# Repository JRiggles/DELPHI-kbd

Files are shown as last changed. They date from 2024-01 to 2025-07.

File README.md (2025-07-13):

<p align="center">
    DELPHI_KBD logo in white
</p>

Hardware v1.0.2, Software v1.2.0 &copy; 2022-25[^1] 

*Current version runs the latest KMK as of July 13th '25, and CircuitPython version 9.2.8*

[^1]: Hardware/software versions will (try to) adhere to [SEMVER](https://semver.org/). It is my intention that hardware and software which share a `MAJOR` version will be compatible with one another (e.g., hardware version 1.2.3 will still be compatible with software version 1.0.0)

## Dual Ergolinear Low-Profile Human Interface ##
DELPHI is a minimal split mechanical keyboard designed to combine ergonomics and an ortholinear layout into a small form factor.

<p align="center">
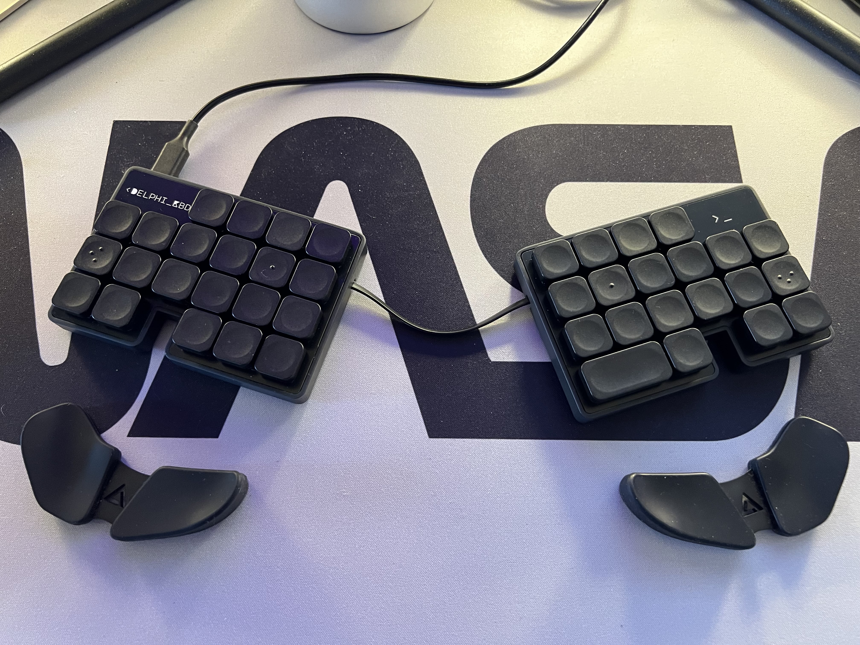
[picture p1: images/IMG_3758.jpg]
Photo of assembled keyboard with PCB plates and the 'HP' version of the 'Edge Case'
    
    <br/>
    <br/>
</p>

<p align="center">
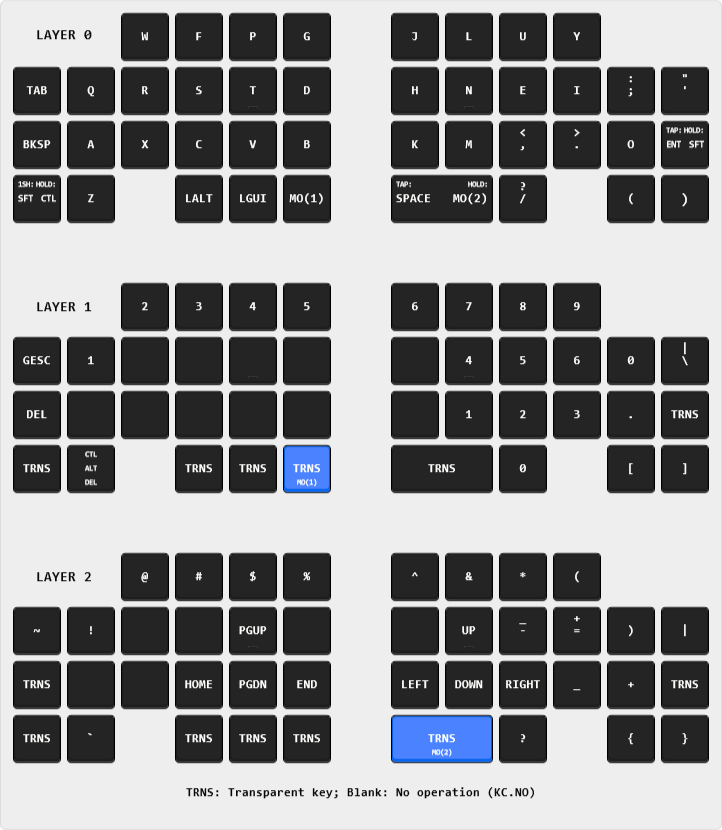
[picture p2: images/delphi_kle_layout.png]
Keyboard Layout Editor layout
    
    <br/>
    <a href="http://www.keyboard-layout-editor.com/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'%3B&@_a:7%3B&=BKSP&=A&=X&=C&=V&=B&_x:1%3B&=K&=M&_a:5%3B&=%3C%0A%0A%0A%0A%0A%0A,&=%3E%0A%0A%0A%0A%0A%0A.&_a:7%3B&=O&_a:4&f:1&fa@:0&:0&:0&:0&:0&:0&:2&:2%3B%3B&=TAP%2F:%0A%0AHOLD%2F:%0A%0A%0A%0AENT%0ASFT%3B&@=1SH%2F:%0A%0AHOLD%2F:%0A%0A%0A%0ASFT%0ACTL&_a:7&f:3%3B&=Z&_x:1%3B&=LALT&=LGUI&=MO(1)&_x:1&a:4&fa@:1&:0&:1%3B&w:2%3B&=TAP%2F:%0A%0AHOLD%2F:%0A%0A%0A%0ASPACE%0AMO(2)&_a:5&f:3%3B&=%3F%0A%0A%0A%0A%0A%0A%2F%2F&_x:1&a:7&f:3%3B&=(&_f:4%3B&=)%3B&@_y:1&c=%23cccccc&t=%23000000&w:2&d:true%3B&=LAYER%201&_c=%231f1f1f&t=%23ffffff&f:3%3B&=2&=3&=4&=5&_x:1%3B&=6&=7&=8&=9%3B&@=GESC&=1&=&=&_n:true%3B&=&=&_x:1%3B&=&_n:true%3B&=4&=5&=6&=0&_a:5%3B&=%7C%0A%0A%0A%0A%0A%0A%5C%3B&@_a:7%3B&=DEL&=&=&=&=&=&_x:1%3B&=&=1&=2&=3&=.&_f:2&fa@:3%3B%3B&=TRNS%3B&@_f:3%3B&=TRNS&_a:5&fa@:1&:1&:0&:0&:0&:0&:1%3B%3B&=CTL%0ADEL%0A%0A%0A%0A%0AALT&_x:1&a:7&f:3%3B&=TRNS&_f:3%3B&=TRNS&_c=%230069ff&a:5&fa@:1&:1%3B%3B&=%0AMO(1)%0A%0A%0A%0A%0ATRNS&_x:1&c=%231f1f1f&a:7&f:3&w:2%3B&=TRNS&_f:3%3B&=0&_x:1&f:3%3B&=%5B&_f:3%3B&=%5D%3B&@_y:1&c=%23cccccc&t=%23000000&f:4&w:2&d:true%3B&=LAYER%202&_c=%231f1f1f&t=%23ffffff&f:3%3B&=%2F@&=%23&=$&=%25&_x:1%3B&=%5E&=%2F&&=*&=(%3B&@=~&=!&=&=&_n:true%3B&=PGUP&=&_x:1%3B&=&_n:true%3B&=UP&_a:5%3B&=%2F_%0A%0A%0A%0A%0A%0A-&=+%0A%0A%0A%0A%0A%0A%2F=&_a:7%3B&=)&=%7C%3B&@=TRNS&=&=&=HOME&=PGDN&=END&_x:1%3B&=LEFT&=DOWN&=RIGHT&=%2F_&=+&_f:2&fa@:3%3B%3B&=TRNS%3B&@_f:3%3B&=TRNS&=%60&_x:1%3B&=TRNS&=TRNS&=TRNS&_x:1&c=%230069ff&a:5&f2:1&w:2%3B&=%0AMO(2)%0A%0A%0A%0A%0ATRNS&_c=%231f1f1f&a:7%3B&=%3F&_x:1%3B&=%7B&=%7D%3B&@_t=%23000000&w:13&d:true%3B&=TRNS%2F:%20Transparent%20key%2F%3B%20Blank%2F:%20No%20operation%20(KC.NO)">Layout</a> (yes, it's <a href="https://en.wikipedia.org/wiki/Colemak">COLEMAK</a>)
</p>

## Features
- "Ergolinear" layout combines an ortholinear (columnar) layout with staggered pinky rows for ergonomics
  - Outermost 2 columns on each half are staggered down 1U for easier reach
- Kailh "Choc" low-profile mechanical switches
- Hot-swappable sockets
- Split board (optional, I suppose)
- 40-42 keys (40%) total [20-21 keys on each half]
- Thumb cluster on each half supports a 3&times;1U or a 1&times;1U + 1&times;2U layout
- Wired connection to PC (either half can be connected via USB)
- Wired connection between Left and Right boards (via Adafruit STEMMA QT)
- Dimensions: 4.65" &times; 3.15" (118mm &times; 80mm) [each half]
- [Adafruit QT Py RP2040 microcontroller](https://www.adafruit.com/product/4900) (2&times;)
  - USB C
  - Raspberry Pi RP2040 chip
  - STEMMA QT connector (a.k.a. Qwiic)
> [!IMPORTANT]
> A [STEMMA QT cable](https://www.adafruit.com/product/5385) (or compatible equivalent, such as a SparkFun Qwiic cable) is required to connect the halves<br/>300mm or 400mm length is recommended. The cable pictured above is 300mm long.
  <br/>

  > DELPHI ***might*** also work with the SAMD21 [Adafruit QT PY](https://www.adafruit.com/product/4600) as long as you solder on the "optional"<sup>*</sup> [2MB SPI Flash IC](https://www.adafruit.com/product/4763), but I haven't been able to get this board to work on Windows 11 (YMMV). 
  >
  > <sup>*</sup>KMK firmware will not fit on this board without the extra Flash memory.

## PCB Renders
<p align="center">
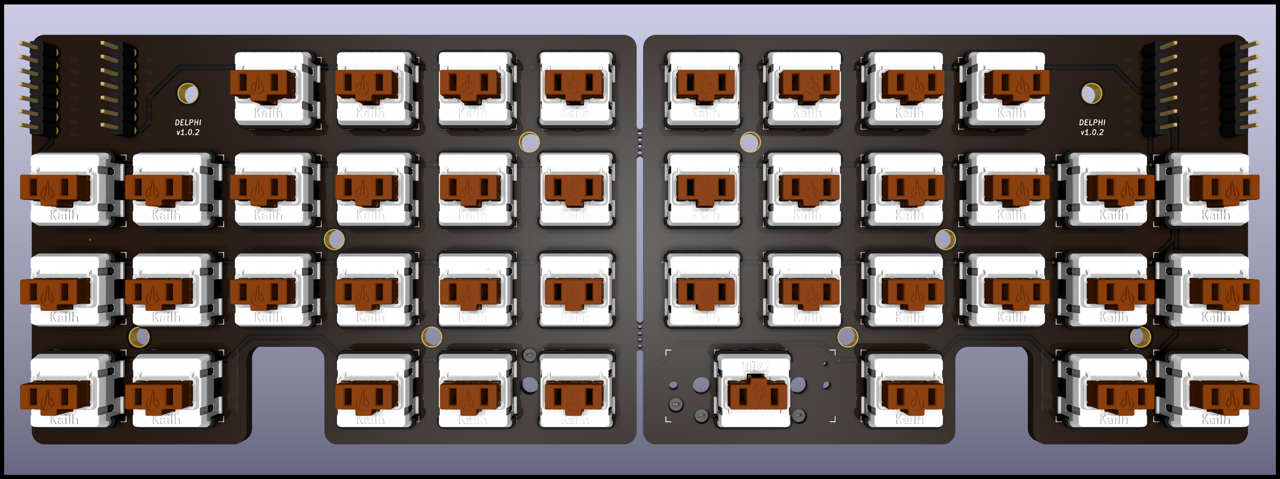
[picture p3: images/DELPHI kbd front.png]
PCB render front view
    
    <br/>
    PCB top view
</p>

<p align="center">
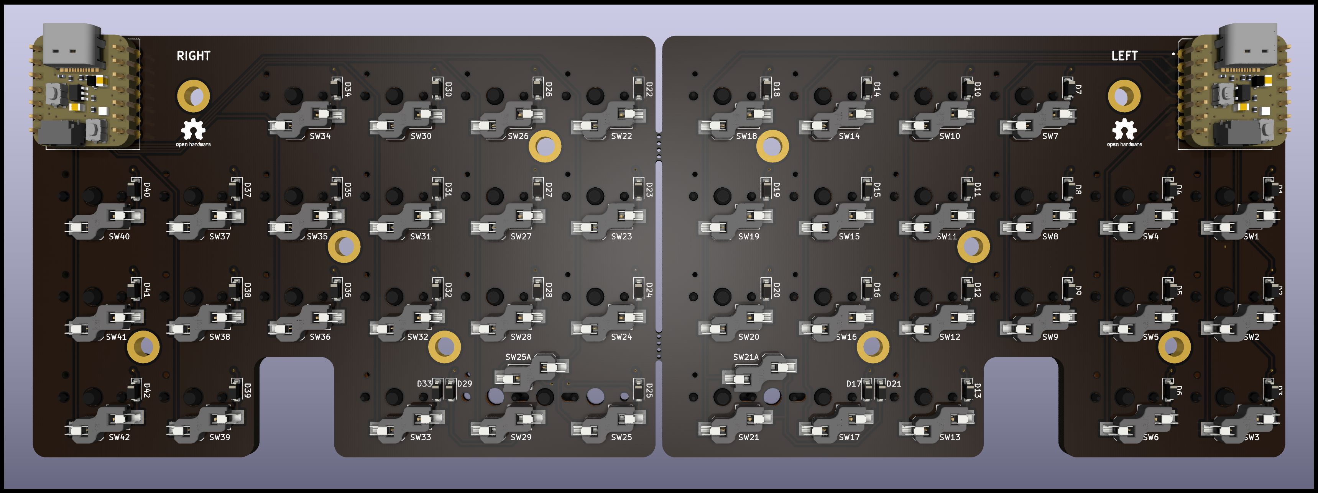
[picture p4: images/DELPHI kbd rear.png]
PCB render rear view
    
    <br/>
    PCB bottom view
</p>

## Accessories
### PCB top and bottom [plates](https://github.com/JRiggles/DELPHI-kbd/blob/main/plates) 
> [!NOTE]
>  - One plate set covers one *half* of DELPHI - you'll need to use two sets to cover both halves
>  - The main PCB mounts to bottom plate via qty. 5 M2&times;6mm standoffs ***per-half***
>  - It's recommended that you use at least the bottom plate on each half of DELPHI in order to protect the components and avoid hitting the microcontroller's reset / boot buttons 
 
<p align="center">
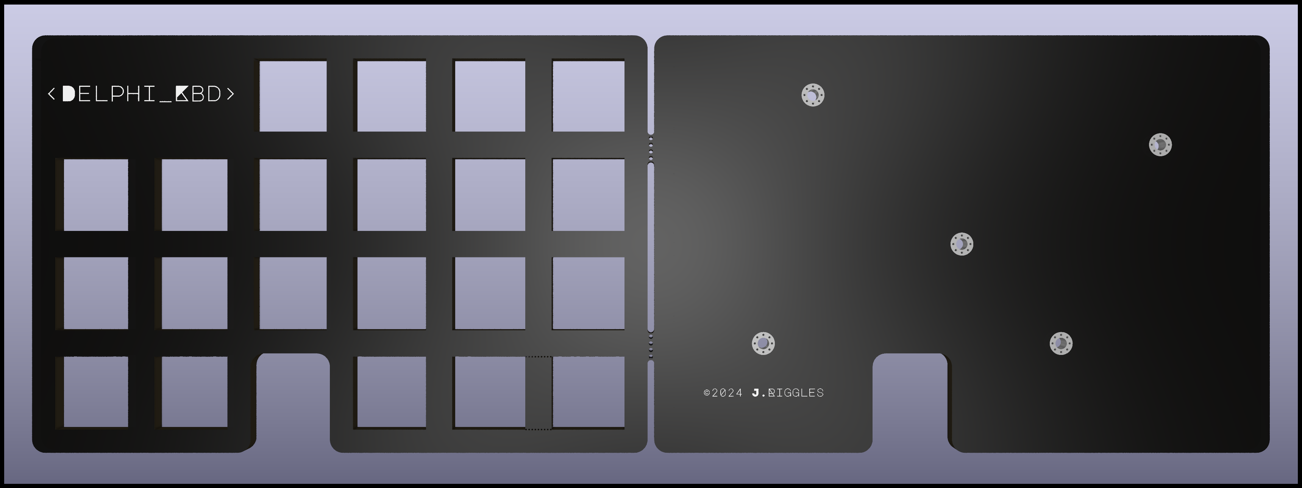
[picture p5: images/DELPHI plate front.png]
PCB render front view
    
    <br/>
    Plates front view (i.e., left side top and bottom plates) - <a href="https://github.com/JRiggles/DELPHI-kbd/blob/main/images/Plates%20LEFT.jpeg">photo here</a>
</p>

<p align="center">
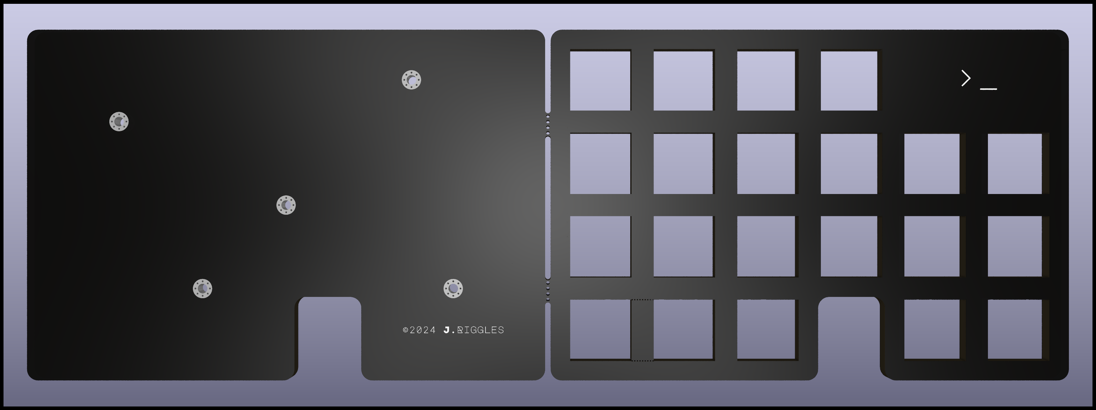
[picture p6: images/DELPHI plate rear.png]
PCB render rear view
    
    <br/>
    Plates rear view (i.e., right side bottom and top plates) - <a href="https://github.com/JRiggles/DELPHI-kbd/blob/main/images/Plates%20RIGHT.jpeg">photo here</a>
</p>

### 3D printable case: the ["Edge Case"](https://github.com/JRiggles/DELPHI-kbd/blob/main/cases) 
> [!NOTE]
>  - This case assumes you're using at least the bottom PCB plate (in addition to the main PCB)
>  - The STL is for the LEFT side; it will need to be *mirrored* in your slicer of choice to accommodate the RIGHT side

There are two case variants:
  - Edge Case LP (low-profile, lines up with bottom plate and main PCB)
  - Edge Case HP (high-profile, lines up with bottom plate and top plate; pictured above on assembled keyboard)
  > Presupported Lychee Slicer scene files (\*.lys) are included for each case variant
  
## Software
- [CircuitPython 8.2.9 or later](https://circuitpython.org/board/adafruit_qtpy_rp2040/)
- [KMK Firmware](https://github.com/KMKfw/kmk_firmware)

## Software Setup

The setup for DELPHI essentially follows the [TL;DR Quick start guide]([https://kmkfw.io/Getting_Started/](https://github.com/KMKfw/kmk_firmware/blob/main/docs/en/Getting_Started.md)) for KMK, with some changes:

1. Connect the **LEFT** half of DELPHI to your computer via USB
2. Download and install [CircuitPython](https://circuitpython.org/board/adafruit_qtpy_rp2040/) for the Adafruit QT Py RP2040
3. [Rename](https://learn.adafruit.com/welcome-to-circuitpython/renaming-circuitpy) the `CIRCUITPY` USB drive to `DELPHI_L` *(must be exactly this!)*
4. Download and unzip [KMK Firmware](https://github.com/KMKfw/kmk_firmware)
5. Download DELPHI [boot.py](https://github.com/JRiggles/DELPHI-kbd/blob/main/firmware/boot.py)
6. Download DELPHI [main.py](https://github.com/JRiggles/DELPHI-kbd/blob/main/firmware/main.py)
7. Copy the `kmk` folder to the root of the `DELPHI_L` drive[^2]
8. Copy `boot.py` to the root of the `DELPHI_L` drive
9. Copy `main.py` to the root of the `DELPHI_L` drive
10. Eject the `DELPHI_L` USB drive and disconnect it from your computer

Repeat these steps for the **RIGHT** half of DELPHI, being sure to rename the `CIRCUITPY` drive to `DELPHI_R` at step 3 *(must be exactly this!)*

[^2]: As of firmware v1.1.0, DELPHI hides the CircuitPython USB drive by default. To mount the drive, hold the corresponding homing key (e.g. "T" on the left half or "N" on the right half) while connecting the board. To disable this feature, simply leave the `boot.py` file empty.

##

### TODO
- [ ] Build guide?

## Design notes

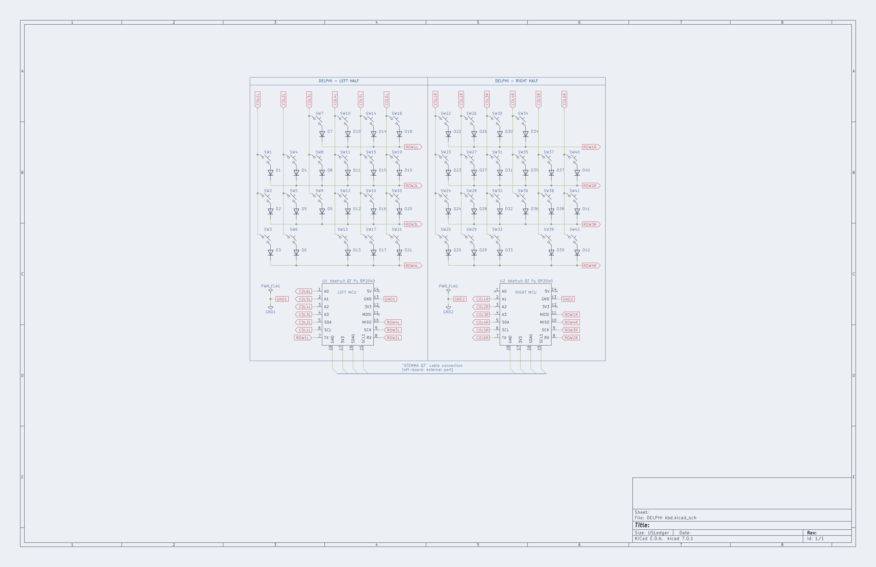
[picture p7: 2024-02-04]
images/schematic.png

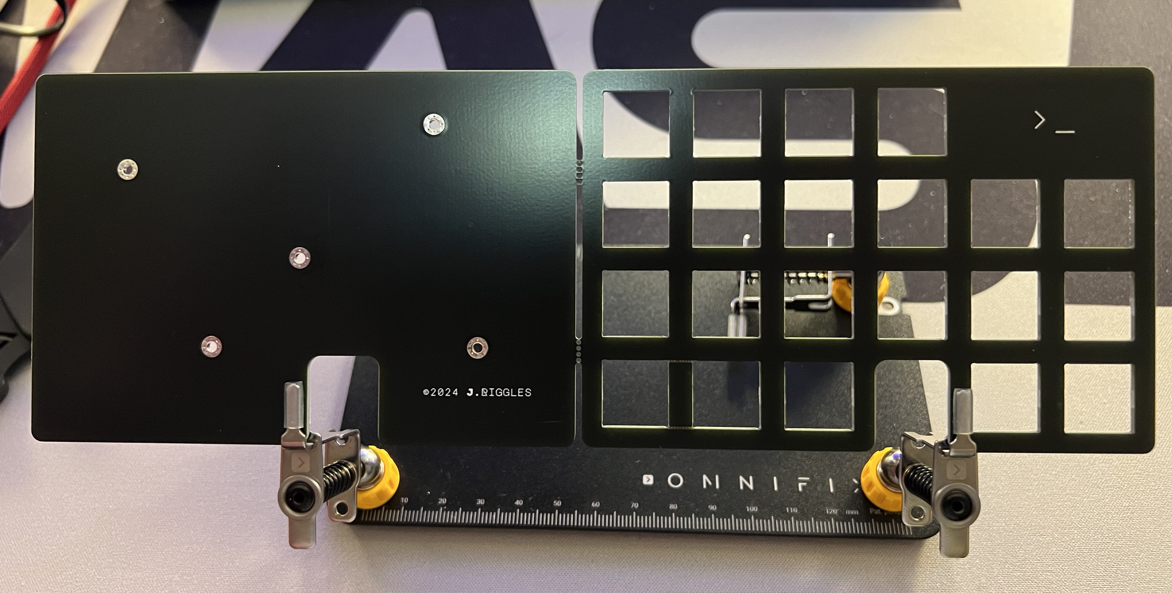
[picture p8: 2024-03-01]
images/Plates RIGHT.jpeg

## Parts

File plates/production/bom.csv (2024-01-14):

Designator | Footprint | Quantity | Value | LCSC Part #
_8, _7, _6, _5, _4, _3, _2, |  | 8
SW23, SW24, SW25, SW26, SW27, SW28, SW29, SW30, SW31, SW32, SW33, SW34, SW35, SW36, SW37_2, SW37, SW38_2, SW38, SW39, SW40, SW42 | SW_Hole | 21 | KEY_SWITCH

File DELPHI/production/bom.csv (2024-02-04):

Designator | Footprint | Quantity | Value | LCSC Part #
_12, _11, _10, _9, _8, _7, _6, _5, _4, _3, _2, |  | 12
D1, D10, D11, D12, D13, D14, D15, D16, D17, D18, D19, D2, D20, D21, D22, D23, D24, D25, D26, D27, D28, D29, D3, D30, D31, D32, D33, D34, D35, D36, D37, D38, D39, D4, D40, D41, D42, D5, D6, D7, D8, D9 | D_SOD-123 | 42 | 1N4148W
SW1, SW10, SW11, SW12, SW13, SW14, SW15, SW16, SW17, SW18, SW19, SW2, SW20, SW21, SW22, SW23, SW24, SW25, SW26, SW27, SW28, SW29, SW3, SW30, SW31, SW32, SW33, SW34, SW35, SW36, SW37, SW38, SW39, SW4, SW40, SW41, SW42, SW5, SW6, SW7, SW8, SW9 | Kailh_socket_PG1350 | 42 | SW_Push_45deg
U1, U2 | Adafruit QT Py RP2040 | 2 | Adafruit QT Py RP2040

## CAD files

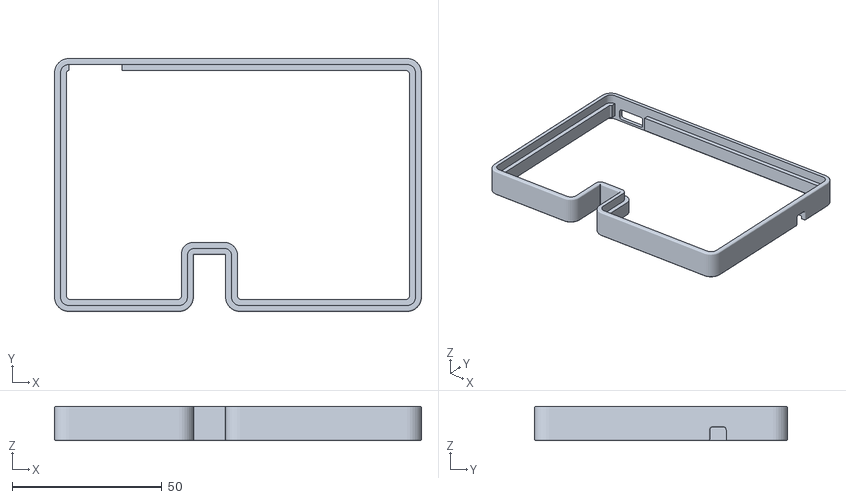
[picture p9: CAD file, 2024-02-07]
cases/DELPHI Edge Case HP.stl
122.6 x 84.5 x 11.5

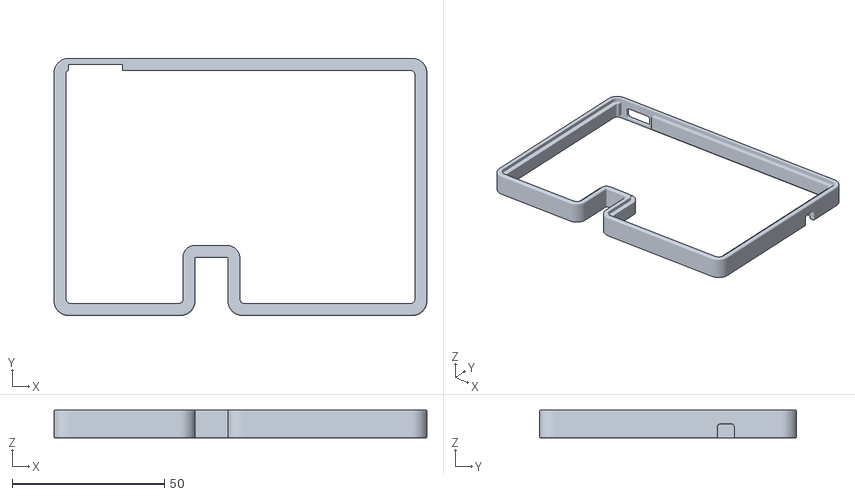
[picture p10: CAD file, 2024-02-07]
cases/DELPHI - Edge Case LP.stl
122.6 x 84.5 x 9.20

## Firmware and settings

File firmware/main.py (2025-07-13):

"""
D.E.L.P.H.I. keyboard - Firmware v1.2.0

MIT License

Copyright (c) 2022-25 John Riggles

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
import board as bd
from storage import getmount

from kmk.extensions.stringy_keymaps import StringyKeymaps
from kmk.keys import KC
from kmk.kmk_keyboard import KMKKeyboard
from kmk.modules.holdtap import HoldTap
from kmk.modules.layers import Layers
from kmk.modules.macros import Delay, Macros, Press, Release
from kmk.modules.split import Split
from kmk.modules.sticky_keys import StickyKeys
from kmk.scanners import DiodeOrientation

keyboard = KMKKeyboard()
# keyboard.debug_enabled = True
keyboard.diode_orientation = DiodeOrientation.COL2ROW
keyboard.rollover_cols_every_rows = 4

# get drive name to determine which row/col pinout to use (left or right)
# so we can use the same main.py for both halves
DRIVE_NAME = getmount('/').label

if DRIVE_NAME == 'DELPHI_L':  # left half
    keyboard.col_pins = (bd.SCL, bd.SDA, bd.A3, bd.A2, bd.A1, bd.A0)
    keyboard.row_pins = (bd.TX, bd.RX, bd.SCK, bd.MISO)
elif DRIVE_NAME == 'DELPHI_R':  # right half
    keyboard.col_pins = (bd.A1, bd.A2, bd.A3, bd.SDA, bd.SCL, bd.TX)
    keyboard.row_pins = (bd.MOSI, bd.RX, bd.SCK, bd.MISO)
else:
    raise RuntimeError(
        f'Unrecognized CircuitPython drive name "{DRIVE_NAME}"; '
        'must be either "DELPHI_L" or "DELPHI_R"'
    )

# instantiate modules and extensions
keyboard.modules.append(HoldTap())
keyboard.modules.append(Layers())
keyboard.modules.append(Macros())
keyboard.modules.append(StickyKeys())
# enable split - data pin SDA1 is the STEMMA QT data pin
split = Split(data_pin=bd.SDA1, use_pio=True, split_flip=False)
keyboard.modules.append(split)  # enable split
# enable stringy keymaps
stringyKeymaps = StringyKeymaps()
keyboard.extensions.append(stringyKeymaps)

# macros
CTL_ALT_DEL = KC.MACRO(
    Press(KC.LCTL),
    Press(KC.LALT),
    Press(KC.DELETE),
    Delay(25),
    Release(KC.LCTL),
    Release(KC.LALT),
    Release(KC.DELETE),
)
# hold-tap keys
SHIFT_CTRL = KC.HT(KC.SK(KC.LSHIFT), KC.LCTRL)  # tap LSHIFT, hold LCTRL
SHIFT_ENTER = KC.HT(KC.ENTER, KC.RSHIFT, prefer_hold=True)

# keymap
keyboard.keymap = [
    [  # layer 0 (default)
        # row 1 left                                        # row 1 right
        'NO', 'NO', 'W', 'F', 'P', 'G',                     'J', 'L', 'U', 'Y', 'NO', 'NO',
        # row 2 left                                        # row 2 right
        'TAB', 'Q', 'R', 'S', 'T', 'D',                     'H', 'N', 'E', 'I', 'SCOLON', 'QUOTE',
        # row 3 left                                        # row 3 right
        'BSPACE', 'A', 'X', 'C', 'V', 'B',                  'K', 'M', 'COMMA', 'DOT', 'O', SHIFT_ENTER,
        # row 4 left                                        # row 4 right
        SHIFT_CTRL, 'Z',  'NO', 'LALT', 'LGUI', KC.MO(1),   KC.LT(2, KC.SPACE), 'NO', 'SLASH', 'NO', 'LPRN', 'RPRN',
    ],
    [  # layer 1
        # row 1 left                                        # row 1 right
        'NO', 'NO', 'N2', 'N3', 'N4', 'N5',                 'N6', 'N7', 'N8', 'N9', 'NO', 'NO',
        # row 2 left                                        # row 2 right
        'ESCAPE', 'N1', 'NO', 'NO', 'NO', 'NO',             'NO', 'N4', 'N5', 'N6', 'N0', 'BSLASH',
        # row 3 left                                        # row 3 right
        'DELETE', 'NO', 'NO', 'NO', 'NO', 'NO',             'NO', 'N1', 'N2', 'N3', 'DOT', 'TRNS',
        # row 4 left                                            # row 4 right
        'TRNS', CTL_ALT_DEL,  'NO', 'TRNS', 'TRNS', 'TRNS',    'TRNS', 'NO', 'N0', 'NO', 'LBRC', 'RBRC',
    ],
    [  # layer 2
        # row 1 left                                        # row 1 right
        'NO', 'NO', 'AT', 'HASH', 'DOLLAR', 'PERCENT',      'CIRCUMFLEX', 'AMPERSAND', 'ASTERISK', 'LPRN', 'NO', 'NO',
        # row 2 left                                        # row 2 right
        'TILDE', 'EXCLAIM', 'NO', 'NO', 'PGUP', 'NO',       'NO', 'UP', 'MINUS', 'EQUAL', 'RPRN', 'PIPE',
        # row 3 left                                        # row 3 right
        'TRNS', 'NO', 'NO', 'HOME', 'PGDOWN', 'END',        'LEFT', 'DOWN', 'RGHT', 'UNDS', 'PLUS', 'TRNS',
        # row 4 left                                        # row 4 right
        'TRNS', 'GRAVE',  'NO', 'TRNS', 'TRNS', 'TRNS',     'TRNS', 'NO', 'QUESTION', 'NO', 'LCBR', 'RCBR',
    ],
]


if __name__ == '__main__':
    keyboard.go()

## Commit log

2022-12-01 init: DELPHI project
    [DELPHI-B_Cu.gbr, DELPHI-B_Mask.gbr, DELPHI-B_Paste.gbr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]
2022-12-01 Update DELPHI.kicad_pcb
    Remove TODO comment
2022-12-01 Update DELPHI.kicad_sch
    Update title block
    [DELPHI.kicad_sch]
2022-12-01 Add images dir, schematic image, front and rear PCB renders
2022-12-03 Add ground plane stitching vias, regenerate plot files
    [DELPHI-B_Cu.gbr, DELPHI-B_Mask.gbr, DELPHI-B_Paste.gbr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]
2022-12-04 Update port label directions
    [DELPHI.kicad_sch]
2024-01-13 Update README.md
    Add note re: CircuitPython version
2024-01-13 Add photo of assembled keyboard
    Top plate not included
2024-01-13 Reupload board photo as PNG
2024-01-14 add kicad files for pcb plates
    [DELPHI Plates.kicad_pcb, DELPHI Plates.kicad_sch]
2024-01-14 Add production files
    [bom.csv, designators.csv, positions.csv]
2024-01-14 add plate renders
2024-01-14 Update README.md w/ plate renders
2024-01-14 add updated kicad files
    bump PCB to rev 1.0.1 - fix mounting hole placement on right half
    [DELPHI kbd.kicad_sch]
2024-01-14 add v1.0.1 production files
    fix an issue w/ mounting hole placement on right half
    [bom.csv, designators.csv, positions.csv]
2024-01-14 fix argumented keys for stringy keymaps (bump: 1.0.2)
    [main.py]
2024-01-17 Update KiCAD files (specifically the schematic)
    [DELPHI kbd.kicad_sch]
2024-01-17 Update schematic image
2024-02-04 Update PCB renders for 1.0.2; clean up schematic
2024-02-04 Update project files for 1.0.2 revision
    Change mounting holes to accommodate PEM P/N: SMTSOB-M2-6ET (M2x6mm SMT standoff); update diode P/N to 1N4148W; clean up silkscreen placement
    [DELPHI kbd.kicad_sch]
2024-02-04 Update Production files for 1.0.2 revision
    [bom.csv, designators.csv, positions.csv]
2024-02-04 Fix version number silkscreen on right half
2024-02-07 Add case STLs and Lychee Slicer scenes
    [DELPHI - Edge Case LP.stl, DELPHI Edge Case HP.stl]
2024-02-18 Update boot.py
    DELPHI now hides the CircuitPython USB drive by default. To mount the drive, hold the corresponding homing key (e.g. "T" on the left half or "N" on the right half) while connecting the board.
2024-02-29 Update main.py - 1.1.1
    Layout tweaks for quality of life; set rollover_cols_every_rows = 4, because it's a 4-row board, bump 1.1.1
2024-03-01 Add PCB photos
    Photos of front/rear v1.0.2 PCB w/ SMT diodes assembled; photos of PCB plates front/rear
2024-03-01 Update README.md
    Add links to photos of finished PCB plates
2024-05-12 Update main.py
    Bump to v1.1.2: fix some keycode issues after kmk update, remove defunct shift key binds on right half, light cleanup
    [main.py]
2024-05-12 Update README.md
    Fix incorrect description of which case is pictured
